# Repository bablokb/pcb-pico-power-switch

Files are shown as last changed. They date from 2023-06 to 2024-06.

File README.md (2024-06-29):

Pico Power Switch
=================

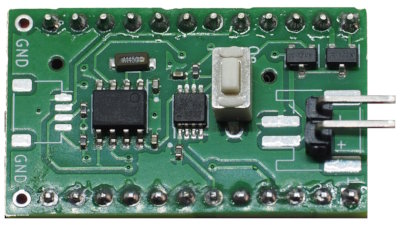
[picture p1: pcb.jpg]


This is a simple breakout to switch the battery power for a Raspberry
Pi Pico to minimize battery usage.

Functions:

  * Enable using a button, a RTC or an external signal
  * Disable by pulling a GPIO high from your program
  * keep time

The target application of this design is a program that runs in
intervals. After startup the program executes it's tasks, sets the
next wakup time and then pulls the "done"-GPIO high.  The circuitry
then cuts power, thus limiting the battery consumption to a very low
level. Measured current draw in off-mode is about 0.35µA.

The design of the breakout allows it to be connected directly on the bottom
side of the Pico.

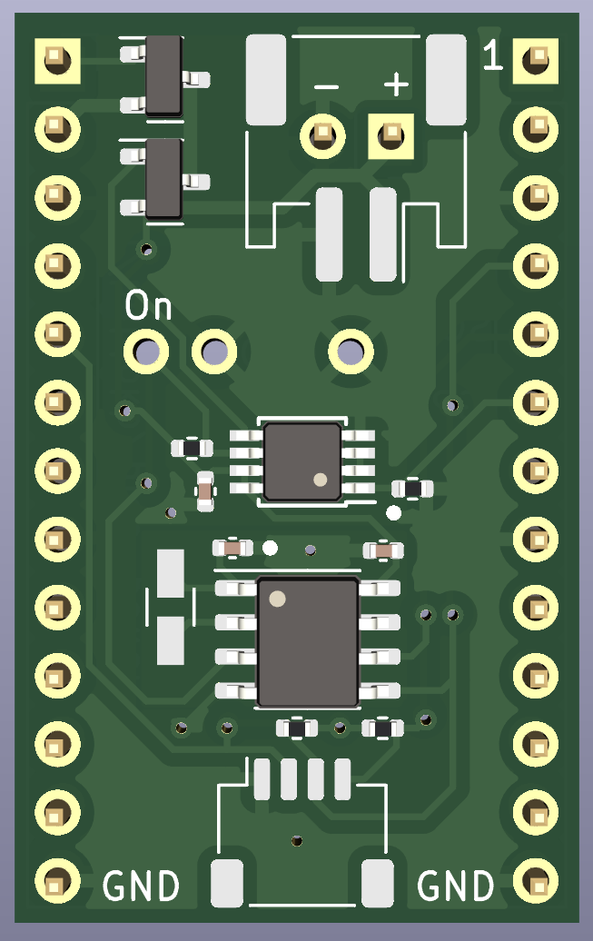
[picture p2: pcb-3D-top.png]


Hardware Components
-------------------

A D-type flip-flop drives the gate of a p-channel mosfet and
switches power (source: battery, drain: VSYS). 
A button, the RTC or an external signal will reset the flip-flop.
This will pull the gate low, thus enabling power.

The "done"-pin of the Pico is connected to the CLK-pin of
the flip-flop. A rising edge will toggle the output and pull
the gate high, which in turn cuts power.

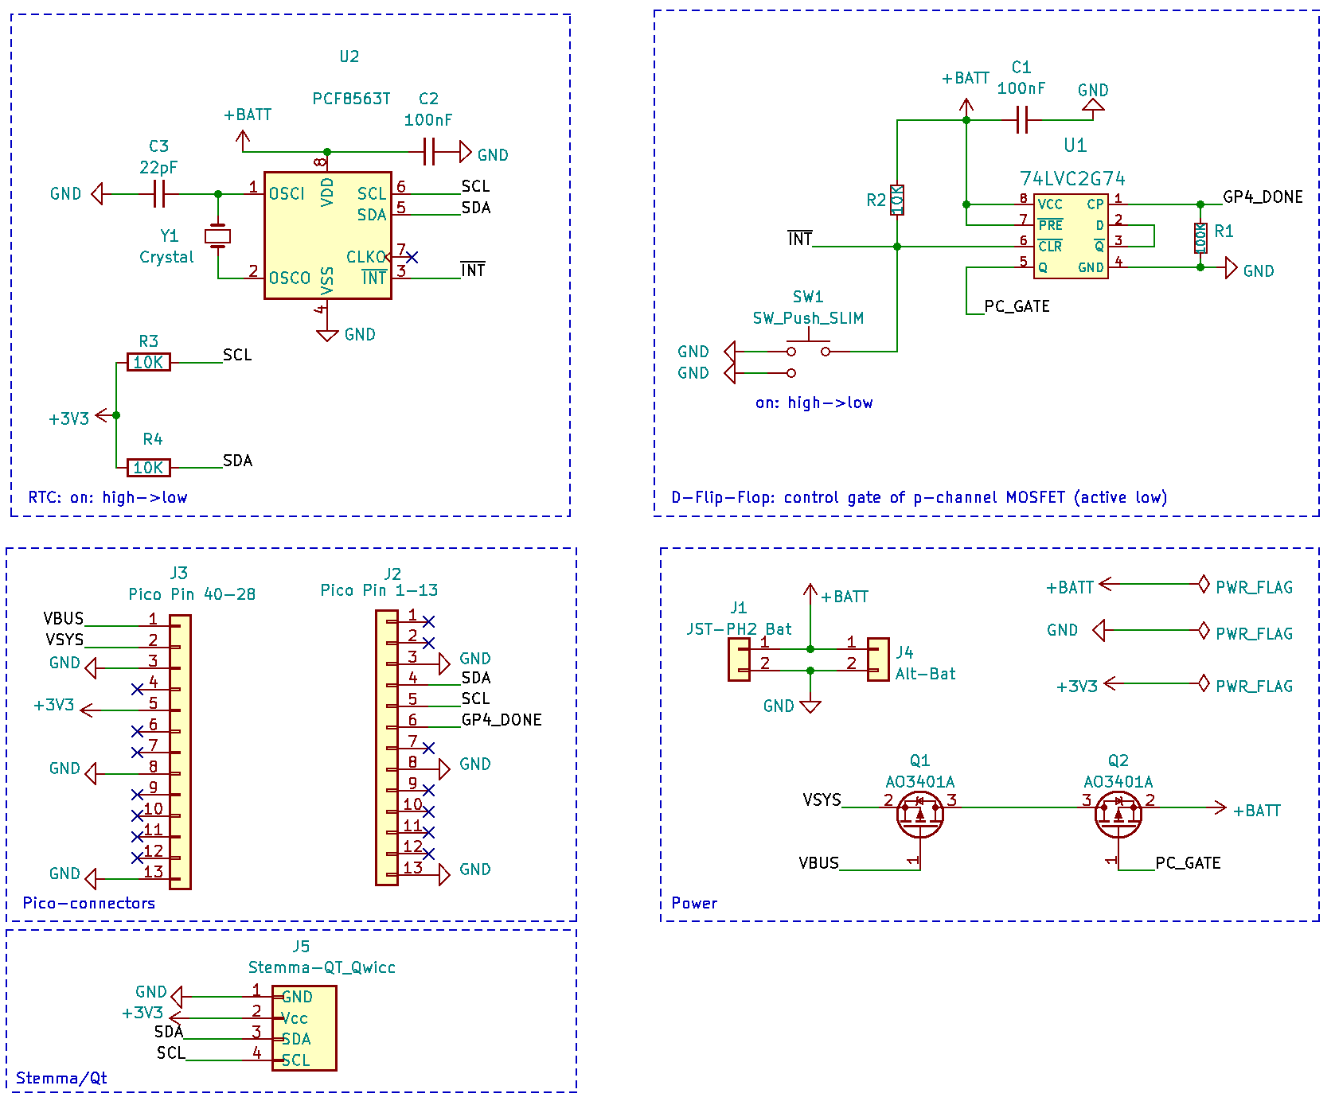
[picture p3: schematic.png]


A second p-channel mosfet will prevent back-powering from VBUS
in case the Pico is connected using the USB-connector. The
voltage-drop across this mosfet is about 0.1V.

PCB
---

PCB design files are in `pico-power-switch.kicad`.

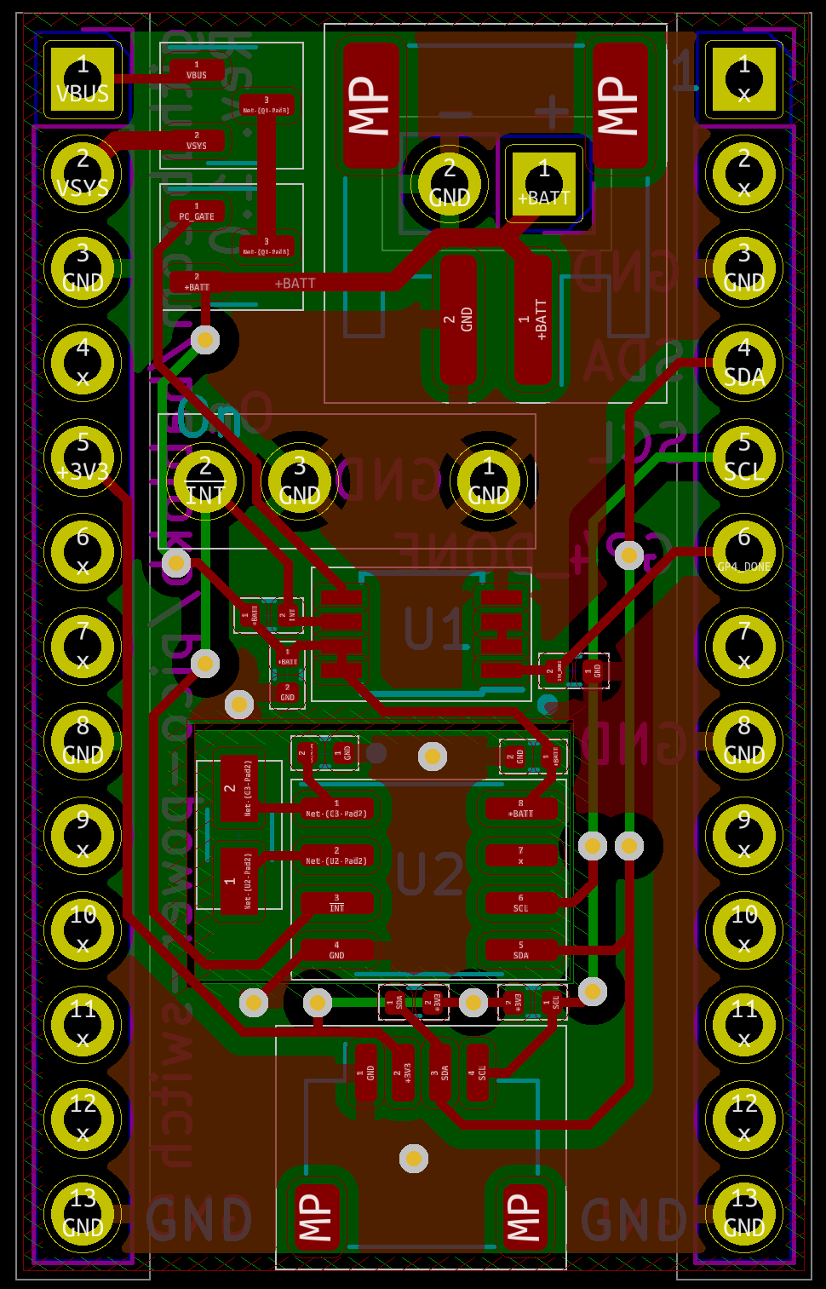
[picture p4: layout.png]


Ready to use production files for JLCPCB are in `production_files`.

Software
--------

A simple example program implemented in CircuitPython
is provided in `src/main.py`. The software provides some boilerplate
code for timer and alarm-based wake up.

In timer-mode, the program uses the countdown-timer of the rtc. It
blinks the on-board LED for ten seconds, then goes to sleep for 15 seconds.

For longer intervals alarm-based wake up is more suitable. Since the rtc
does not support seconds for alarms, it will always fire on "full minutes".

Measured current
----------------

Using a Nordic-PPK2, a Pico-W running with 3.6V draws an average
current of 0.35µA:

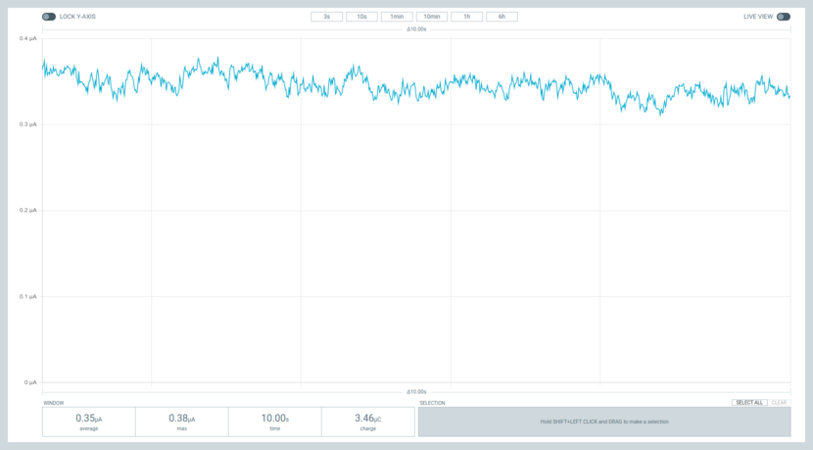
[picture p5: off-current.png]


License
-------

[![CC BY-SA 4.0][cc-by-sa-shield]][cc-by-sa]

This work is licensed under a
[Creative Commons Attribution-ShareAlike 4.0 International
License][cc-by-sa].

[][cc-by-sa]

[cc-by-sa]: http://creativecommons.org/licenses/by-sa/4.0/
[cc-by-sa-image]: https://licensebuttons.net/l/by-sa/4.0/88x31.png
[cc-by-sa-shield]:
https://img.shields.io/badge/License-CC%20BY--SA%204.0-lightgrey.svg

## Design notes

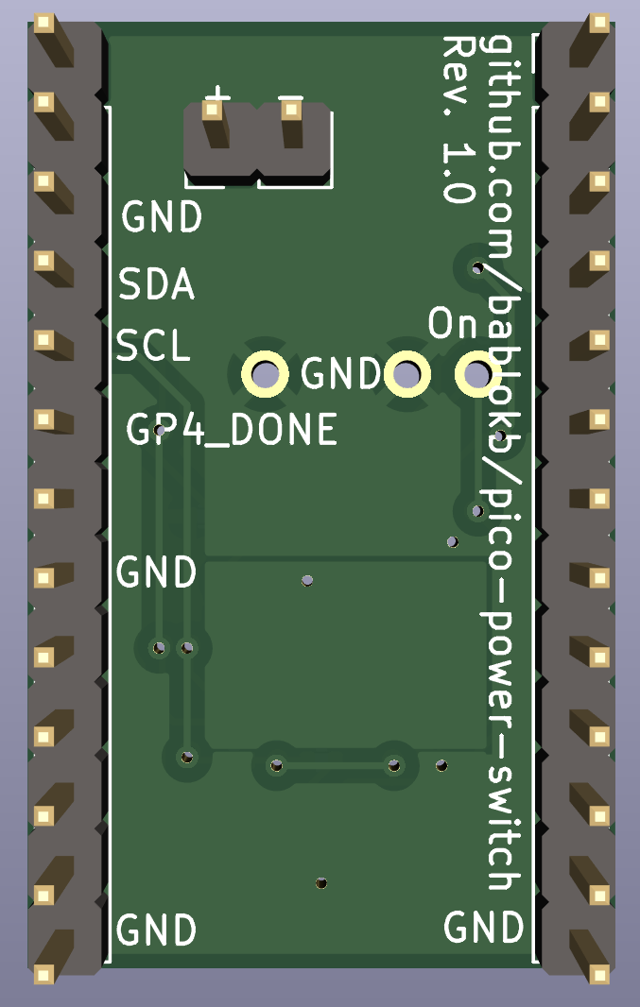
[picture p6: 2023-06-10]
pcb-3D-bottom.png

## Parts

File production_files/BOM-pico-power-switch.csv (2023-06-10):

Comment | Designator | Footprint | LCSC
AO3401A | Q1,Q2 | SOT-23 | C15127
100nF | C1,C2 | C_0402_1005Metric | C1525
22pF | C3 | C_0402_1005Metric | C1555
100K | R1 | R_0402_1005Metric | C25741
10K | R2,R3,R4 | R_0402_1005Metric | C25744
74LVC2G74 | U1 | TSSOP-8_3x3mm_P0.65mm | C282355
Crystal | Y1 | Crystal_SMD_3215-2Pin_3.2x1.5mm | C32346
PCF8563T | U2 | SOIC-8_3.9x4.9mm_P1.27mm | C7440

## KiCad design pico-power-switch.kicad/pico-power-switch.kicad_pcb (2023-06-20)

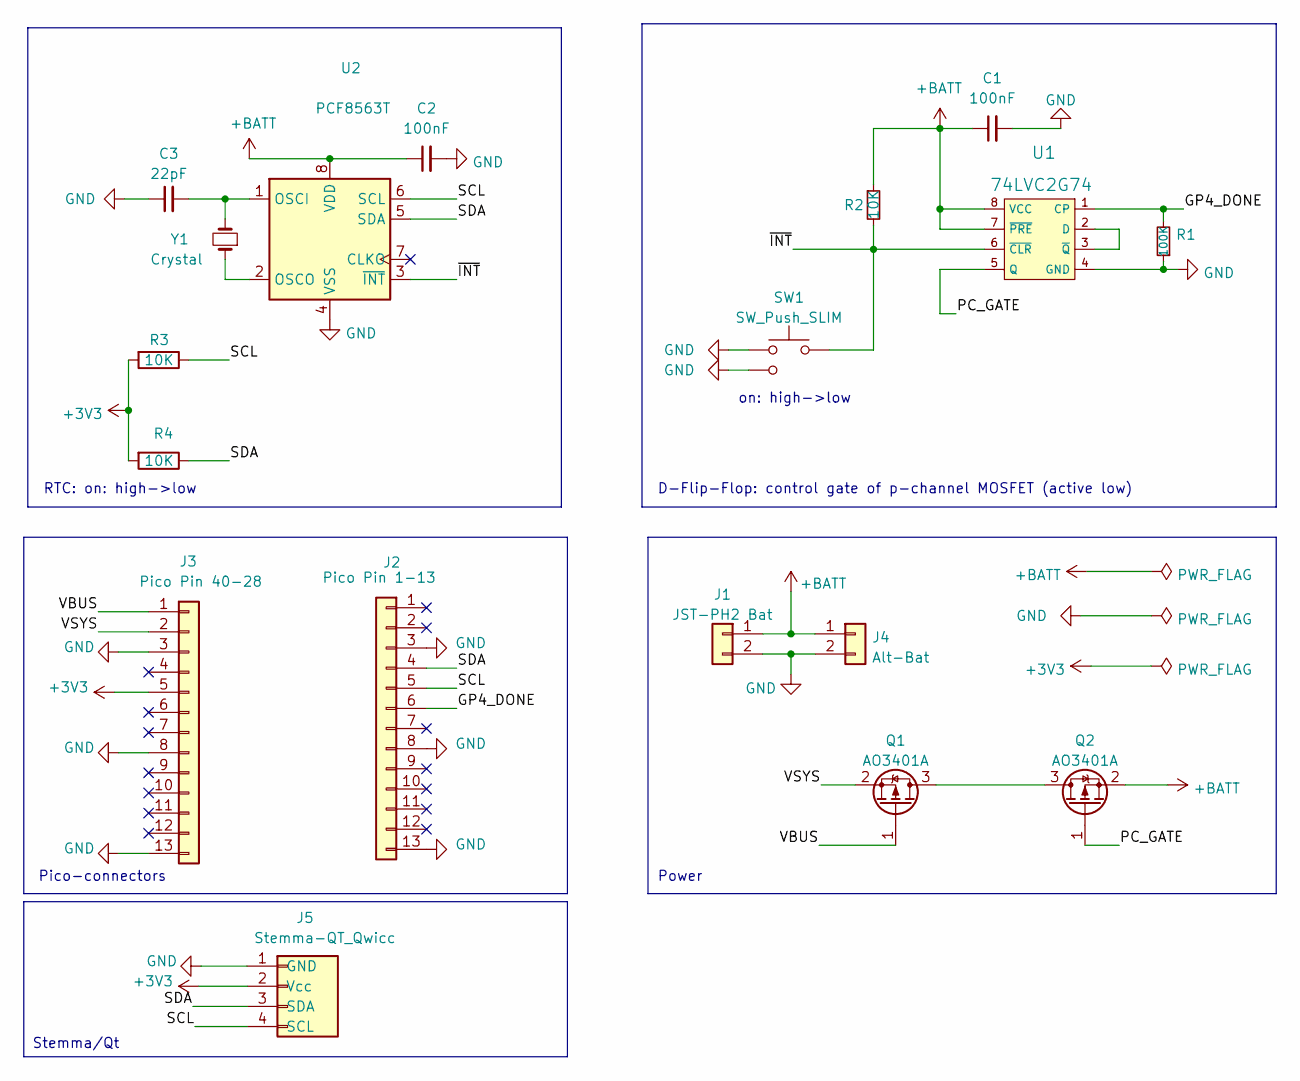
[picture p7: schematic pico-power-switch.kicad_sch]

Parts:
C1, C2: 100nF; C_0402_1005Metric; LCSC C1525
C3: 22pF; C_0402_1005Metric; LCSC C1555
J1: JST-PH2 Bat; JST_PH_S2B-PH-SM4-TB_1x02-1MP_P2.00mm_Horizontal
J2: Pico Pin 1-13; PinHeader_1x13_P2.54mm_Vertical
J3: Pico Pin 40-28; PinHeader_1x13_P2.54mm_Vertical
J4: Alt-Bat; PinHeader_1x02_P2.54mm_Vertical
J5: Stemma-QT_Qwicc; JST_SH_SM04B-SRSS-TB_1x04-1MP_P1.00mm_Horizontal
Q1, Q2: AO3401A; SOT-23; LCSC C15127
R1: 100K; R_0402_1005Metric; LCSC C25741
R2, R3, R4: 10K; R_0402_1005Metric; LCSC C25744
SW1: SW_Push_SLIM; SW_PUSH_SLIM_1x4
U1: 74LVC2G74; TSSOP-8_3x3mm_P0.65mm; MPN SN74HC74N; Digi-Key_PN 296-1602-5-ND
U2: PCF8563T; SOIC-8_3.9x4.9mm_P1.27mm; LCSC C7440
Y1: Crystal; Crystal_SMD_3215-2Pin_3.2x1.5mm; LCSC C32346

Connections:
+3V3: J3.5, J5.2 (Vcc), R3.2, R4.2
+BATT: C1.1, C2.1, J1.1, J4.1, Q2.2 (S), R2.1, U1.7 (~PRE), U1.8 (VCC), U2.8 (VDD)
/GP4_DONE: J2.6, R1.2, U1.1 (CP)
/PC_GATE: Q2.1 (G), U1.5 (Q)
/SCL: J2.5, J5.4 (SCL), R3.1, U2.6 (SCL)
/SDA: J2.4, J5.3 (SDA), R4.1, U2.5 (SDA)
/VBUS: J3.1, Q1.1 (G)
/VSYS: J3.2, Q1.2 (S)
/~INT: R2.2, SW1.2, U1.6 (~CLR), U2.3 (~INT)
GND: C1.2, C2.2, C3.1, J1.2, J2.3, J2.8, J2.13, J3.3, J3.8, J3.13, J4.2, J5.1 (GND), R1.1, SW1.1, SW1.3 (1), U1.4 (GND), U2.4 (VSS)
unnamed: C3.2, U2.1 (OSCI), Y1.2
unnamed: Q1.3 (D), Q2.3 (D)
unnamed: U1.2 (D), U1.3 (~Q)
unnamed: U2.2 (OSCO), Y1.1

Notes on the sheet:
Power
D-Flip-Flop: control gate of p-channel MOSFET (active low)
Pico-connectors
RTC: on: high->low
Stemma/Qt
on: high->low

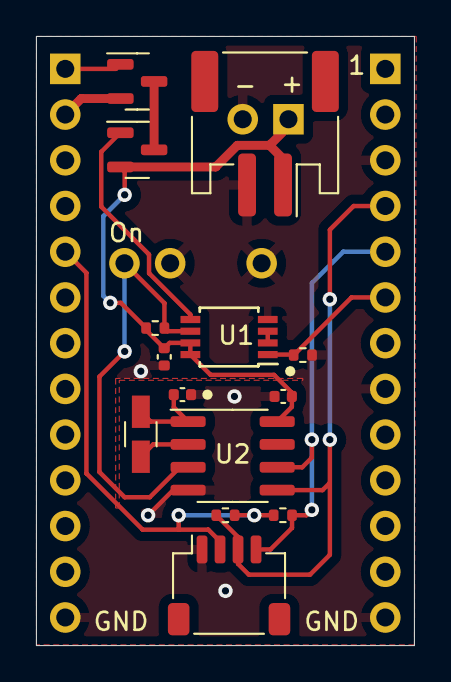
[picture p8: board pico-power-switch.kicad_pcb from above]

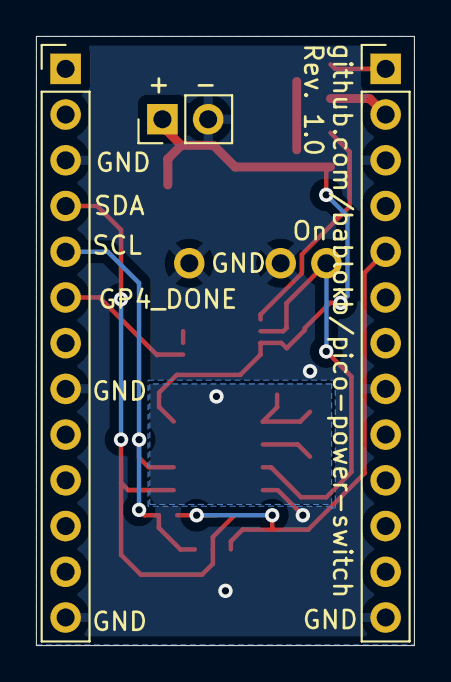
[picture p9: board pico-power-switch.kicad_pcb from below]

Board: 2 copper layers, 21.0 x 33.8 mm, 18 parts (3 on the bottom side), 14 nets.

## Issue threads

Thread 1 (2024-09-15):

Example circuit controlling external chip

mosheliv, 2024-09-15:
can you please add a diagram how this should be wired to turn off and on an external (not pico) mcu? like esp32 :)

bablokb, 2024-09-17:
This depends on the specific MCU. Which one do you have?

mosheliv, 2024-09-17:
Esp32 cam but should be general diagram. Where to connect power, etc.

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

bablokb, 2024-09-17:
I think GND, SDA/SCL and done pin are clear (and not specific). Otherwise, it *is* important what the device actually gives you. If you only have a 5V-inout pin, you would connect VSYS to 5V-inout and either add a schottky, or a jumper in between. If your device has a BAT-in pin, then you would connect VSYS to the BAT-in pin. Depending on the device, you would connect USB/5V to VBUS, but if Bat-in is already protected internally, you don't need to.

So without specific knowledge of the device and without a schematic, it is hard to give sound advice.

mosheliv, 2024-09-23:
I see you have esp32c3... so do i and it would be great for me.

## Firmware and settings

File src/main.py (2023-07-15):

#-----------------------------------------------------------------------------
# Test program.
#
# The program supports two modes:
#
# timer-mode: blink the onboard LED for 10 seconds, then goe to sleep
#             and wakes up again after 15 seconds.
#
# alarm-mode: blink the onboard LED for 10 seconds, then goe to sleep
#             and wake up at the start of the next minute
#
# The countdown-timer of the RTC and works on a PCF8563 up to
# 15300 seconds (i.e. 255m or 4h15m). For longer intervals than
# 255 minutes use the alarm or switch to the PCF8523.
#
# Author: Bernhard Bablok
#
# Website: https://github.com/pcb-pico-en-control
#-----------------------------------------------------------------------------

OFF_MODE_TIMER = 0      # 0: use alarm, 1: use timer

import time
import board
import alarm
from digitalio import DigitalInOut, Direction, Pull

# imports for PCF8563
import busio
if OFF_MODE_TIMER:
  from adafruit_pcf8563.timer import Timer as PCF_RTC
else:
  from adafruit_pcf8563.pcf8563 import PCF8563 as PCF_RTC

# --- configuration   --------------------------------------------------------

PIN_DONE = board.GP4   # connect to 74HC74 CLK
PIN_SDA  = board.GP2   # connect to RTC
PIN_SCL  = board.GP3   # connect to RTC

LED_TIME = 0.5         # blink-duration
ON_TIME  = 10          # seconds on (blinking)
OFF_TIMER = 15         # seconds off (<= 15300 == 255*60)
OFF_ALARM = 1          # wake up in x minutes

# --- create hardware objects   ----------------------------------------------

led            = DigitalInOut(board.LED)
led.direction  = Direction.OUTPUT

done           = DigitalInOut(PIN_DONE)
done.direction = Direction.OUTPUT
done.value     = 0

i2c = busio.I2C(PIN_SCL,PIN_SDA)
rtc = PCF_RTC(i2c)

# --- simulate work   --------------------------------------------------------

def blink(dur=LED_TIME,repeat=1):
  while repeat:
    led.value = 1
    time.sleep(dur)
    led.value = 0
    time.sleep(dur)
    repeat -= 1

# --- set timer   ------------------------------------------------------------

def set_timer(secs):
  if secs < 256:
    rtc.timer_frequency = rtc.TIMER_FREQ_1HZ
    rtc.timer_value = secs
  else:
    rtc.timer_frequency = rtc.TIMER_FREQ_1_60HZ
    rtc.timer_value = min(255,int(secs/60)+1)
  
  # enable timer and interrupt
  rtc.timer_interrupt = True
  rtc.timer_enabled   = True

# --- set alarm   ------------------------------------------------------------

def set_alarm(minutes):
  alarm_time = time.mktime(rtc.datetime) + 60*minutes
  rtc.alarm  = (time.localtime(alarm_time),"daily")
  rtc.alarm_interrupt = True

# --- main program   ---------------------------------------------------------

# disable timer interrupt and clear timer/alarm
if OFF_MODE_TIMER:
  rtc.timer_status    = False
  rtc.timer_pulsed    = False
  rtc.timer_interrupt = False
  rtc.timer_enabled   = False
else:
  rtc.alarm_status     = False
  rtc.alarm_interrupt  = False
  rtc.clockout_enabled = False
  if rtc.lost_power:
    rtc.datetime =time.struct_time((2022,10,3,13,5,12,0,277,-1))

# Simulate some work by blinking the LED
active_until = time.monotonic() + ON_TIME
print("working...")
while time.monotonic() < active_until:
  blink()

# finished working, set timer or alarm and exit
if OFF_MODE_TIMER:
  set_timer(OFF_TIMER)
else:
  set_alarm(OFF_ALARM)

done.value = 1 # signal "done" to external circuit - this should turn us off
time.sleep(0.001)
done.value = 0
time.sleep(0.5)

# this won't happen (it should not)
blink(LED_TIME/3,4)
time.sleep(2)

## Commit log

2023-06-10 Rev 1.0 (in production)
    [BOM-pico-power-switch.csv, pico-power-switch.kicad_pcb, pico-power-switch.kicad_sch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]
2023-06-20 fixed schematic for power-connectors
    [pico-power-switch.kicad_pcb, pico-power-switch.kicad_sch]
2024-06-03 added image of the PCB
2024-06-29 document current measurement
